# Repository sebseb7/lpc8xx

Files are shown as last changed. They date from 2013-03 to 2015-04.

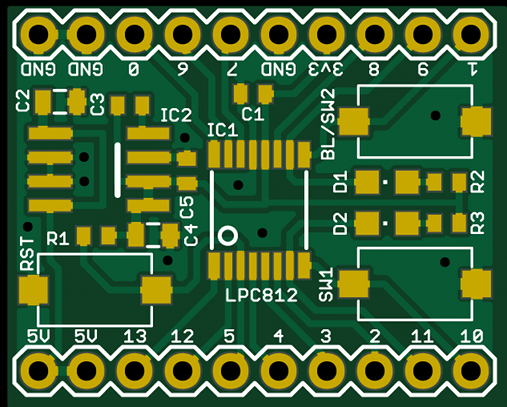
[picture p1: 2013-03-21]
eagle/lpc812.png

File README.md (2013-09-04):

endorse (http://coderwall.com/sebseb7)

lpc8xx_template
===============

template project with makefile, flash script and eval board.

- - - 

####lpc812 features:

* Cortex-M0+ Core
* 30 Mhz
* 16kb flash (lpc811: 8kb)
* 4kb RAM (lpc811: 2kb)
* USART Bootloader and SerialWireDebugging ( make debug )
* ROM drivers for USART, i2c and power profiles
* 14 hihgly configurable GPIO Pins (you can connect UART, I2C and SPI to any pin)
* 3 * USART , 2 * SPI , 1 * I2C
* internal RC with 1% accuracy
* while(1); @ 30 Mhz ==> 5.5mA

- - -

lpc812

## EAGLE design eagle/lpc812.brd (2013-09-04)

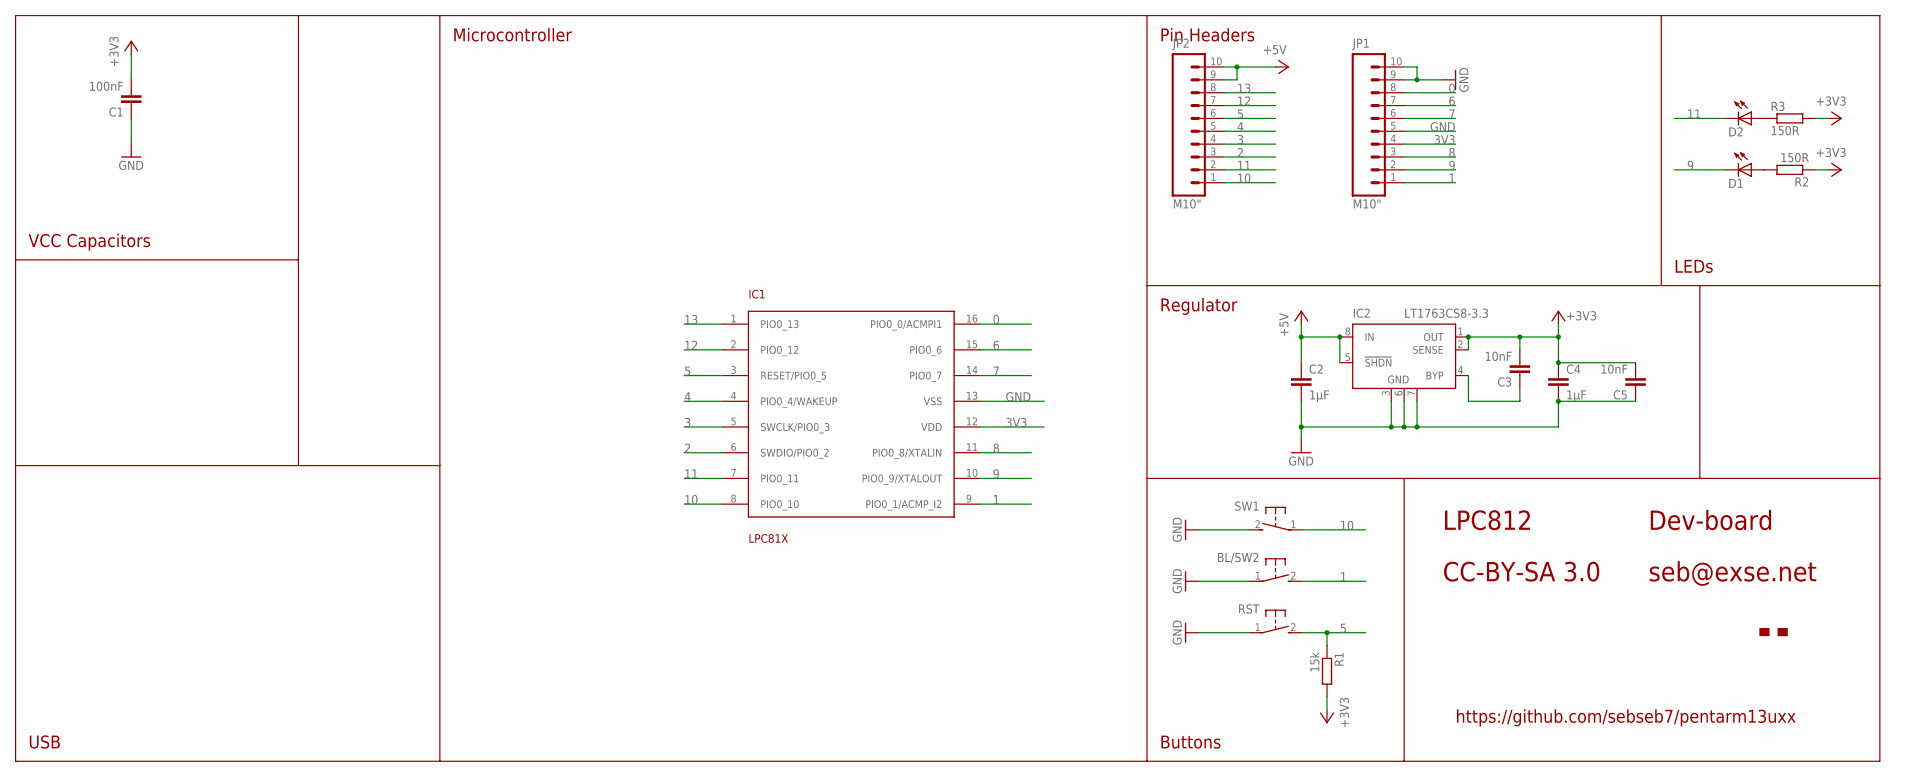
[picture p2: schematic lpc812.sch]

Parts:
BL/SW2: SWITCH_MCTAEF
C1: 100nF; C0402
C2, C4: 1µF; 0805
C3, C5: 10nF; C0402
D1, D2: LEDCHIPLED_0805; CHIPLED_0805
IC1: LPC81X; TSSOP16
IC2: LT1763CS8-3.3; SOIC8
JP1, JP2: M10"; 1X10
R1: 15k; R0402
R2, R3: 150R; R0402
RST: SWITCH_MCTAEF
SW1: SWITCH_MCTAEF
U$1: MAKE-DD_LOGO'PROMPT'; MAKE-DD_LOGO_PROMPT

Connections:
0: IC1.16 (PIO0_0/ACMPI1), JP1.8
1: BL/SW2.2, IC1.9 (PIO0_1/ACMP_I2), JP1.1
2: IC1.6 (SWDIO/PIO0_2), JP2.3
3: IC1.5 (SWCLK/PIO0_3), JP2.4
3V3: C1.2, C3.2, C4.1, C5.2, IC1.12 (VDD), IC2.1 (OUT), IC2.2 (SENSE), JP1.4, R1.2, R2.1, R3.2
4: IC1.4 (PIO0_4/WAKEUP), JP2.5
5: IC1.3 (RESET/PIO0_5), JP2.6, R1.1, RST.2
6: IC1.15 (PIO0_6), JP1.7
7: IC1.14 (PIO0_7), JP1.6
8: IC1.11 (PIO0_8/XTALIN), JP1.3
9: D1.C, IC1.10 (PIO0_9/XTALOUT), JP1.2
10: IC1.8 (PIO0_10), JP2.1, SW1.1
11: D2.C, IC1.7 (PIO0_11), JP2.2
12: IC1.2 (PIO0_12), JP2.7
13: IC1.1 (PIO0_13), JP2.8
+5V: C2.1, IC2.5 (!SHDN), IC2.8 (IN), JP2.9, JP2.10
GND: BL/SW2.1, C1.1, C2.2, C4.2, C5.1, IC1.13 (VSS), IC2.3 (GND), IC2.6 (GND), IC2.7 (GND), JP1.5, JP1.9, JP1.10, RST.1, SW1.2
unnamed: C3.1, IC2.4 (BYP)
unnamed: D1.A, R2.2
unnamed: D2.A, R3.1

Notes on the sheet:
Pin Headers
Regulator
Buttons
LEDs
Microcontroller
VCC Capacitors
USB
CC-BY-SA 3.0
seb@exse.net
LPC812
Dev-board
https://github.com/sebseb7/pentarm13uxx

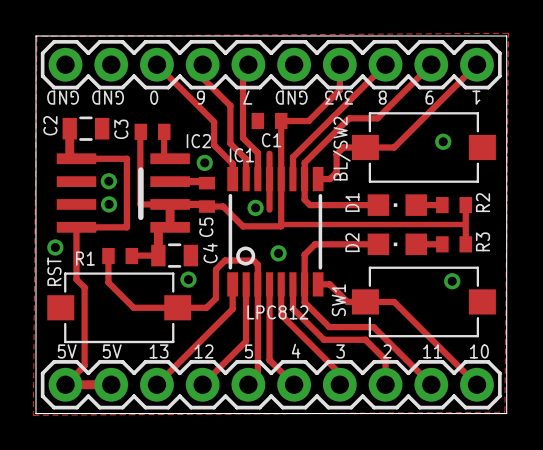
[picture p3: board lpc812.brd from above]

Board: 2 copper layers, 26.1 x 21.0 mm, 18 parts (1 on the bottom side), 20 nets.

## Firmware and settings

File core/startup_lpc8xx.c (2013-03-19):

//*****************************************************************************
//   +--+
//   | ++----+
//   +-++    |
//     |     |
//   +-+--+  |
//   | +--+--+
//   +----+    Copyright (c) 2012 Code Red Technologies Ltd.
//
// LPC8xx Microcontroller Startup code for use with Red Suite
//
// Version : 121107
//
// Software License Agreement
//
// The software is owned by Code Red Technologies and/or its suppliers, and is
// protected under applicable copyright laws.  All rights are reserved.  Any
// use in violation of the foregoing restrictions may subject the user to criminal
// sanctions under applicable laws, as well as to civil liability for the breach
// of the terms and conditions of this license.
//
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
//*****************************************************************************

#define WEAK __attribute__ ((weak))
#define ALIAS(f) __attribute__ ((weak, alias (#f)))

#include "LPC8xx.h"

//*****************************************************************************
#if defined (__cplusplus)
extern "C" {
#endif

//*****************************************************************************
//
// Forward declaration of the default handlers. These are aliased.
// When the application defines a handler (with the same name), this will
// automatically take precedence over these weak definitions
//
//*****************************************************************************
     void ResetISR(void);
WEAK void NMI_Handler(void);
WEAK void HardFault_Handler(void);
WEAK void SVC_Handler(void);
WEAK void PendSV_Handler(void);
WEAK void SysTick_Handler(void);
WEAK void IntDefaultHandler(void);

//*****************************************************************************
//
// Forward declaration of the specific IRQ handlers. These are aliased
// to the IntDefaultHandler, which is a 'forever' loop. When the application
// defines a handler (with the same name), this will automatically take
// precedence over these weak definitions
//
//*****************************************************************************
void SPI0_IRQHandler(void) ALIAS(IntDefaultHandler);
void SPI1_IRQHandler(void) ALIAS(IntDefaultHandler);
void UART0_IRQHandler(void) ALIAS(IntDefaultHandler);
void UART1_IRQHandler(void) ALIAS(IntDefaultHandler);
void UART2_IRQHandler(void) ALIAS(IntDefaultHandler);
void I2C_IRQHandler(void) ALIAS(IntDefaultHandler);
void SCT_IRQHandler(void) ALIAS(IntDefaultHandler);
void MRT_IRQHandler(void) ALIAS(IntDefaultHandler);
void CMP_IRQHandler(void) ALIAS(IntDefaultHandler);
void WDT_IRQHandler(void) ALIAS(IntDefaultHandler);
void BOD_IRQHandler(void) ALIAS(IntDefaultHandler);
void WKT_IRQHandler(void) ALIAS(IntDefaultHandler);
void PININT0_IRQHandler(void) ALIAS(IntDefaultHandler);
void PININT1_IRQHandler(void) ALIAS(IntDefaultHandler);
void PININT2_IRQHandler(void) ALIAS(IntDefaultHandler);
void PININT3_IRQHandler(void) ALIAS(IntDefaultHandler);
void PININT4_IRQHandler(void) ALIAS(IntDefaultHandler);
void PININT5_IRQHandler(void) ALIAS(IntDefaultHandler);
void PININT6_IRQHandler(void) ALIAS(IntDefaultHandler);
void PININT7_IRQHandler(void) ALIAS(IntDefaultHandler);
//*****************************************************************************
//
// The entry point for the application.
// main() is the entry point for Newlib based applications
//
//*****************************************************************************
extern int main(void);
//*****************************************************************************
//
// External declaration for the pointer to the stack top from the Linker Script
//
//*****************************************************************************
extern void _vStackTop(void);

//*****************************************************************************
#if defined (__cplusplus)
} // extern "C"
#endif
//*****************************************************************************
//
// The vector table.
// This relies on the linker script to place at correct location in memory.
//
//*****************************************************************************
extern void (* const g_pfnVectors[])(void);
__attribute__ ((section(".isr_vector")))
void (* const g_pfnVectors[])(void) = {
	// Core Level - CM0plus
	&_vStackTop, // The initial stack pointer
	ResetISR,							// The reset handler
	NMI_Handler,							// The NMI handler
	HardFault_Handler,						// The hard fault handler
	0,								// Reserved
	0,								// Reserved
	0,								// Reserved
	0,								// Reserved
	0,								// Reserved
	0,								// Reserved
	0,								// Reserved
	SVC_Handler,							// SVCall handler
	0,								// Reserved
	0,								// Reserved
	PendSV_Handler,							// The PendSV handler
	SysTick_Handler,						// The SysTick handler

	// Chip Level - LPC8xx
    SPI0_IRQHandler,                         // SPI0 controller
	SPI1_IRQHandler,                         // SPI1 controller
	0,                                       // Reserved
	UART0_IRQHandler,                        // UART0
	UART1_IRQHandler,                        // UART1
	UART2_IRQHandler,                        // UART2
	0,                                       // Reserved
	0,                                       // Reserved
	I2C_IRQHandler,                          // I2C controller
	SCT_IRQHandler,                          // Smart Counter Timer
	MRT_IRQHandler,                          // Multi-Rate Timer
	CMP_IRQHandler,                          // Comparator
	WDT_IRQHandler,                          // PIO1 (0:11)
	BOD_IRQHandler,                          // Brown Out Detect
	0,                                       // Reserved
	WKT_IRQHandler,                          // Wakeup timer
	0,                                       // Reserved
	0,                                       // Reserved
	0,                                       // Reserved
	0,                                       // Reserved
	0,                                       // Reserved
	0,                                       // Reserved
	0,                                       // Reserved
	0,                                       // Reserved
	PININT0_IRQHandler,                      // PIO INT0
	PININT1_IRQHandler,                      // PIO INT1
	PININT2_IRQHandler,                      // PIO INT2
	PININT3_IRQHandler,                      // PIO INT3
	PININT4_IRQHandler,                      // PIO INT4
	PININT5_IRQHandler,                      // PIO INT5
	PININT6_IRQHandler,                      // PIO INT6
	PININT7_IRQHandler,                      // PIO INT7
}; /* End of g_pfnVectors */ 


//*****************************************************************************
// The following symbols are constructs generated by the linker, indicating
// the location of various points in the "Global Section Table". This table is
// created by the linker via the Code Red managed linker script mechanism. It
// contains the load address, execution address and length of each RW data
// section and the execution and length of each BSS (zero initialized) section.
//*****************************************************************************
extern unsigned int _etext;
extern unsigned int _data;
extern unsigned int _edata;
extern unsigned int _bss;
extern unsigned int _ebss;


//*****************************************************************************
// Reset entry point for your code.
// Sets up a simple runtime environment and initializes the C/C++
// library.
//*****************************************************************************
__attribute__ ((section(".after_vectors")))
void
ResetISR(void) {
	
	unsigned int *src, *dst;
	
	/* Copy data section from flash to RAM */
	src = &_etext;
	dst = &_data;
	while (dst < &_edata)
		*dst++ = *src++;

	/* Clear the bss section */
	dst = &_bss;
	while (dst < &_ebss)
		*dst++ = 0;

	SystemInit();
	main();

	while (1) {
		;
	}
}

//*****************************************************************************
// Default exception handlers. Override the ones here by defining your own
// handler routines in your application code.
//*****************************************************************************
__attribute__ ((section(".after_vectors")))
void NMI_Handler(void)
{
    while(1)
    {
    }
}
__attribute__ ((section(".after_vectors")))
void HardFault_Handler(void)
{
    while(1)
    {
    }
}
__attribute__ ((section(".after_vectors")))
void SVCall_Handler(void)
{
    while(1)
    {
    }
}
__attribute__ ((section(".after_vectors")))
void PendSV_Handler(void)
{
    while(1)
    {
    }
}
__attribute__ ((section(".after_vectors")))
void SysTick_Handler(void)
{
    while(1)
    {
    }
}

//*****************************************************************************
//
// Processor ends up here if an unexpected interrupt occurs or a specific
// handler is not present in the application code.
//
//*****************************************************************************
__attribute__ ((section(".after_vectors")))
void IntDefaultHandler(void)
{
    while(1)
    {
    }
}

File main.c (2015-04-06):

#include "main.h"

/*
 * 	datasheet: http://www.nxp.com/documents/data_sheet/LPC81XM.pdf
 *  user manual: http://www.nxp.com/documents/user_manual/UM10601.pdf
 *  swtich matrix tool: http://www.lpcware.com/content/nxpfile/nxp-switch-matrix-tool-lpc800 (for pin configuration)
 *
 *
 *  ISP: When pin PIO0_1 is pulled LOW on reset, the part enters ISP mode and the ISP command handler starts up. 
 *       In ISP mode, pin PIO0_0 is connected to function U0_RXD and pin PIO0_4 is connected to function U0_TXD on the USART0 block.
 */

volatile uint32_t msTicks = 0;

void SysTick_Handler(void) {
	msTicks++;
}

#define CPU_RESET_CYCLECOUNTER    do { SCB_DEMCR = SCB_DEMCR | 0x01000000;  \
	DWT_CYCCNT = 0;                      \
	DWT_CTRL = DWT_CTRL | 1 ; } while(0)


void delay_ms(uint32_t ms) {
	uint32_t now = msTicks;
	while ((msTicks-now) < ms);
}

uint32_t divu7(uint32_t n) {
	uint32_t q, r;
	q = (n >> 1) + (n >> 4); q = q + (q >> 6);
	q = q + (q>>12) + (q>>24); 
	q = q >> 2;
	r = n - q*7;
	return q + ((r + 1) >> 3); // return q + (r > 6);
}

#define LED1 9        
#define LED2 11
#define LED 7        

int main(void) {

	SysTick_Config(SystemCoreClock / 1000);


	LPC_GPIO_PORT->DIR0 |= (1<<LED1)|(1<<LED2);    // set pins as output

	while (1)
	{
		LPC_GPIO_PORT->NOT0 = 1<<LED;    // LED output high


		delay_ms(200);

		/*
		   for(uint32_t i = 0; i < 1200000; i++)
		   {
		   uint32_t a = 323243434+i;

		// 6 seconds == 60 cycles
		//uint32_t b = divu7(a);

		// 45 seconds = 450 cycles
		uint32_t b = a / 7;
		//uint32_t b = a >> 2;

		if(b>LPC_GPIO_PORT->PIN0)
		{
		LPC_GPIO_PORT->NOT0 = 1;
		}

		}
		*/

	}

}

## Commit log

2013-03-06 switch tool
2013-03-19 added test board
    [lpc812.brd, lpc812.sch]
2013-03-20 added switch matrix tool
2013-03-20 added python script for uart isp flashing
2013-03-20 final touches
    [lpc812.brd, lpc812.sch]
2013-09-04 make the eval board run at 30Mhz and let LEDs test-blink at 1Hz
2013-09-04 value lables
    [lpc812.brd]

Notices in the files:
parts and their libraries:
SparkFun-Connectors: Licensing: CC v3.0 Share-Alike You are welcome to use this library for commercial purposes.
